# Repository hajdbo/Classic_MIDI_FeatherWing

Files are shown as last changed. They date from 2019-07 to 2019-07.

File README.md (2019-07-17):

# Classic_MIDI_FeatherWing

### _A classic MIDI interface FeatherWing with provisions for DIN-5 and TRS TypeB connectors_

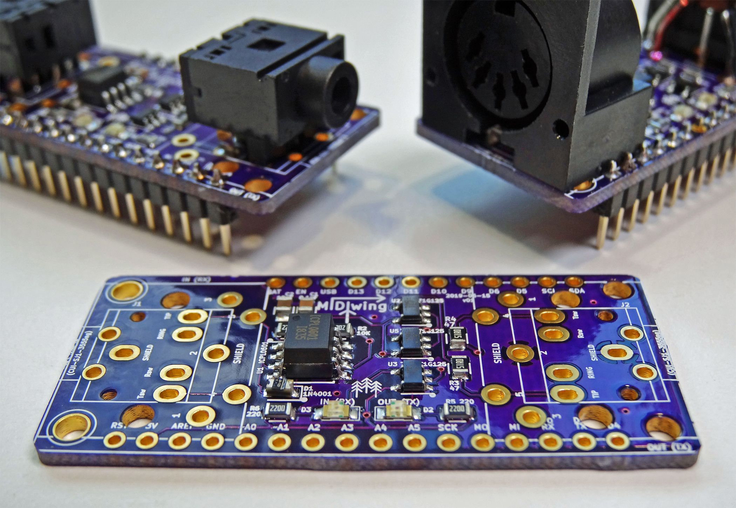
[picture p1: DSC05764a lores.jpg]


The Classic MIDI FeatherWing interface is an Adafruit Feather-compatible module. Deriving its power from the host Feather's 3.3V power, the interface converts incoming and outgoing classic MIDI current-loop input and output to Feather UART (RX and TX) logic pins.

The wing provides on-board input and output footprints for 3.5mm TRS Type B and DIN-5 connectors while maintaining the Feather dimensional format, thanks to John Park's inspirational _Feather MIDI Nub_ design (Twitter: @johnedgarpark). The MIDI input is an optically-isolated connection. MIDI output is buffered and current-limited. On-board receive (RX) and transmit (TX) LEDs indicate incoming and outgoing signals.

DIN-5 MIDI jack used: https://www.adafruit.com/product/1134

3.5mm TRS MIDI jack used: https://www.adafruit.com/product/1699

The Classic MIDI interface was tested with CircuitPython version 4.1.0 beta 1 and earlier releases. Example code is provided in the repository. Additional code examples can be found within the _adafruit__midi_ CircuitPython examples distribution.

OSH Park project: https://oshpark.com/shared_projects/AyVkzfXM

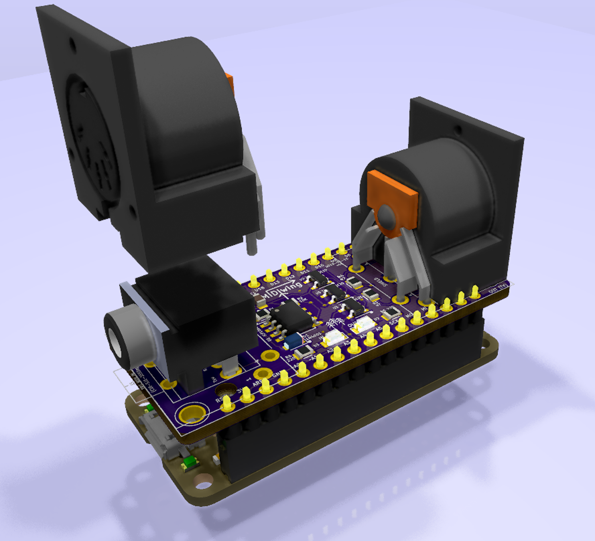
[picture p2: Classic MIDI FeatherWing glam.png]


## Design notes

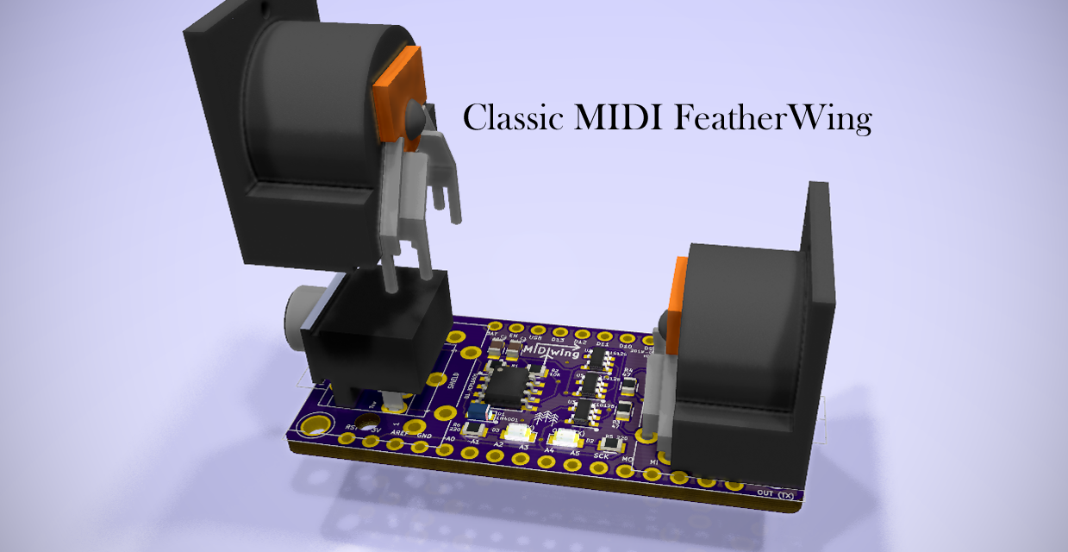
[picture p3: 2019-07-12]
Classic MIDI FeatherWing glam2.png

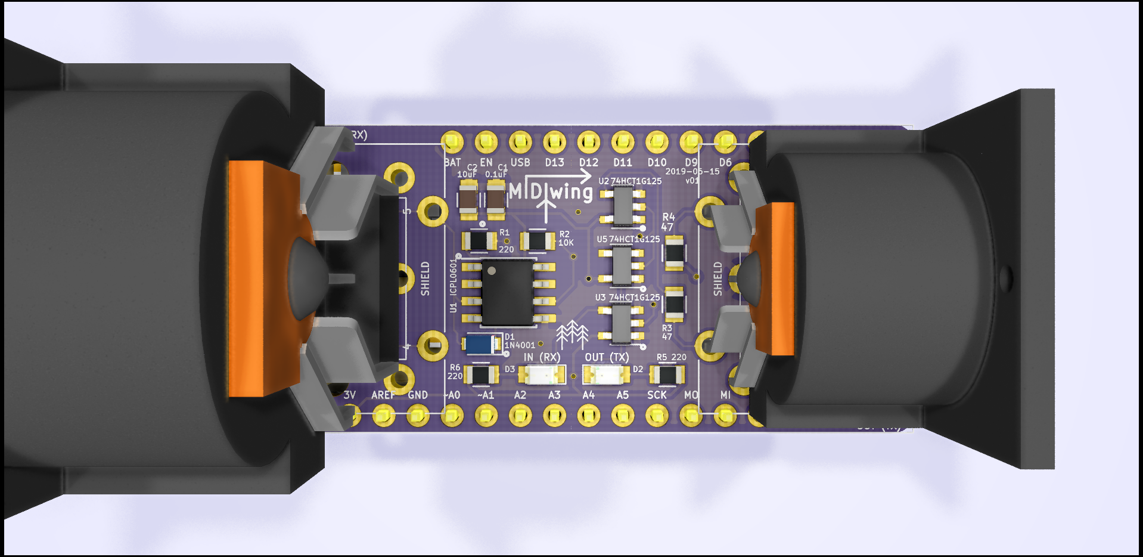
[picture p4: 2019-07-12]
Classic MIDI FeatherWing.png

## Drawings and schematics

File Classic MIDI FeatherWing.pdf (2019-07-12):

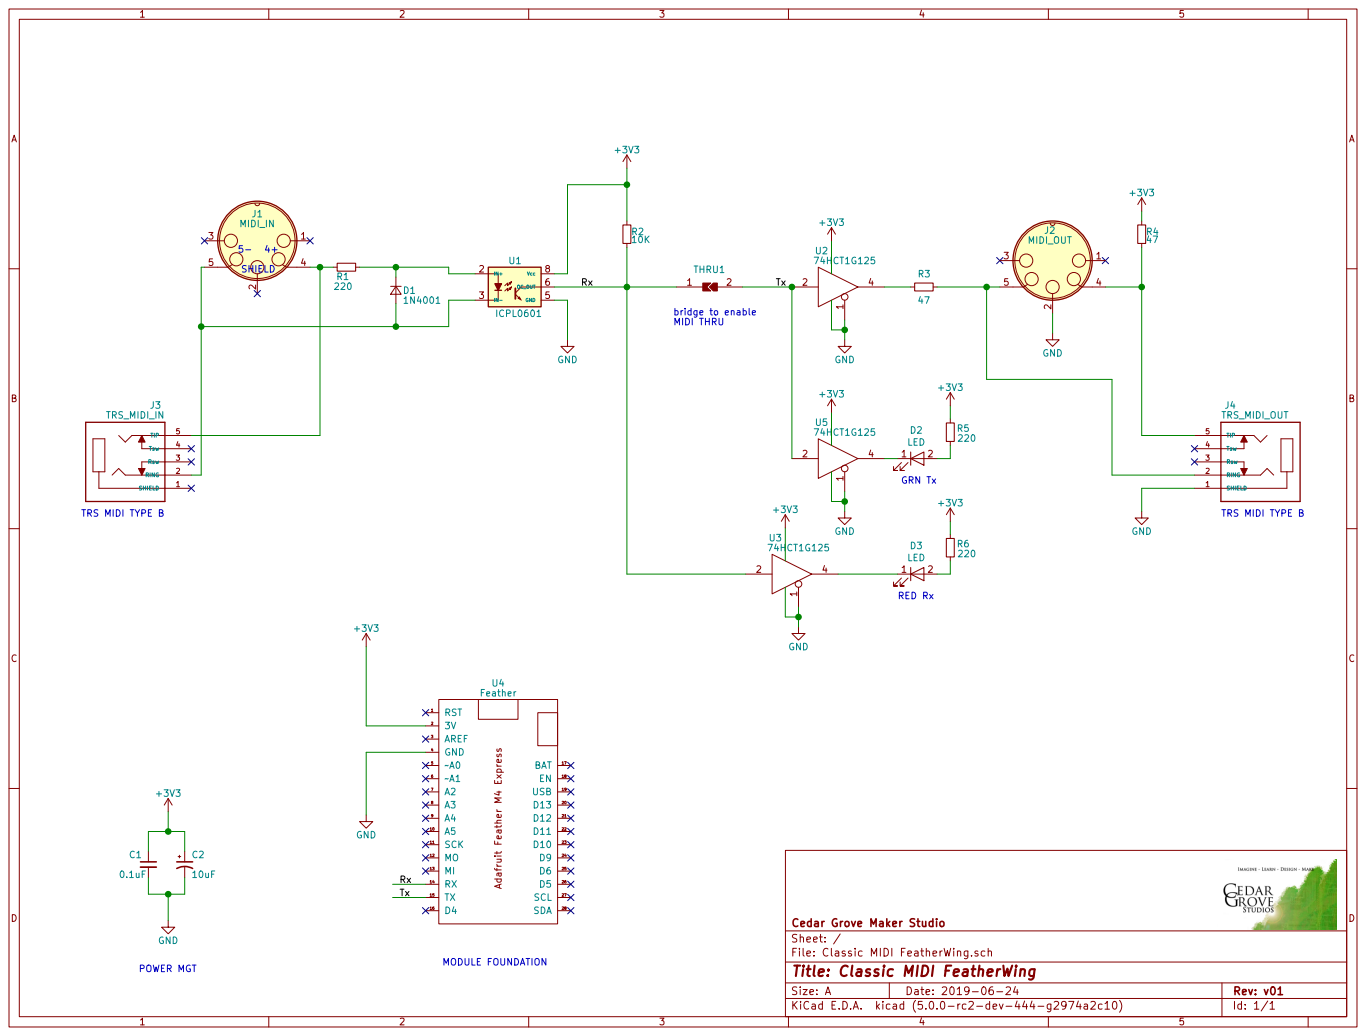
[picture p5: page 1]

220 GRN Tx RED Rx bridge to enable MIDI THRU

File: Classic MIDI FeatherWing.sch Sheet: / Cedar Grove Maker Studio

Id: 1/1 Title: Classic MIDI FeatherWing

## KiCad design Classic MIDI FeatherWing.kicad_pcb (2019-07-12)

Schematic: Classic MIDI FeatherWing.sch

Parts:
C1: 0.1uF; C_0805_HandSoldering
C2: 10uF; C_0805_HandSoldering
D1: 1N4001; D_0805_hand_soldering
D2, D3: LED; LED_0805_HandSoldering
J1: MIDI_IN; CUI_SDS-50J
J2: MIDI_OUT; CUI_SDS-50J
J3: TRS_MIDI_IN; STX-3120-5_3.5mm
J4: TRS_MIDI_OUT; STX-3120-5_3.5mm
R1, R5, R6: 220; R_0805_HandSoldering
R2: 10K; R_0805_HandSoldering
R3, R4: 47; R_0805_HandSoldering
THRU1: Solder_Jumper_0805; 0805_Solder_Jumper
U1: ICPL0601; SOIC-8_3.9x4.9mm_Pitch1.27mm
U2, U3, U5: 74HCT1G125; TSOP-5_1.65x3.05mm_Pitch0.95mm_hand_solder
U4: Feather; Adafruit_Feather_M4_Express_bare

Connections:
+3V3: C1.1, C2.1, R2.1, R4.1, R5.2, R6.2, U1.8 (Vcc), U2.6, U3.6, U4.2, U5.6
/Rx: R2.2, THRU1.1, U1.6 (OC_OUT), U3.2, U4.14
/Tx: THRU1.2, U2.2, U4.15, U5.2
GND: C1.2, C2.2, J2.2, J4.1, U1.5 (GND), U2.1, U2.3, U3.1, U3.3, U4.4, U5.1, U5.3
unnamed: D1.1, R1.2, U1.2 (IN+)
unnamed: D1.2, J1.5, J3.2, U1.3 (IN-)
unnamed: D2.1, U5.4
unnamed: D2.2, R5.1
unnamed: D3.1, U3.4
unnamed: D3.2, R6.1
unnamed: J1.4, J3.5, R1.1
unnamed: J2.4, J4.5, R4.2
unnamed: J2.5, J4.2, R3.1
unnamed: R3.2, U2.4

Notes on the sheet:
SHIELD
POWER MGT
MODULE FOUNDATION
GRN Tx
RED Rx
bridge to enable MIDI THRU
TRS MIDI TYPE B

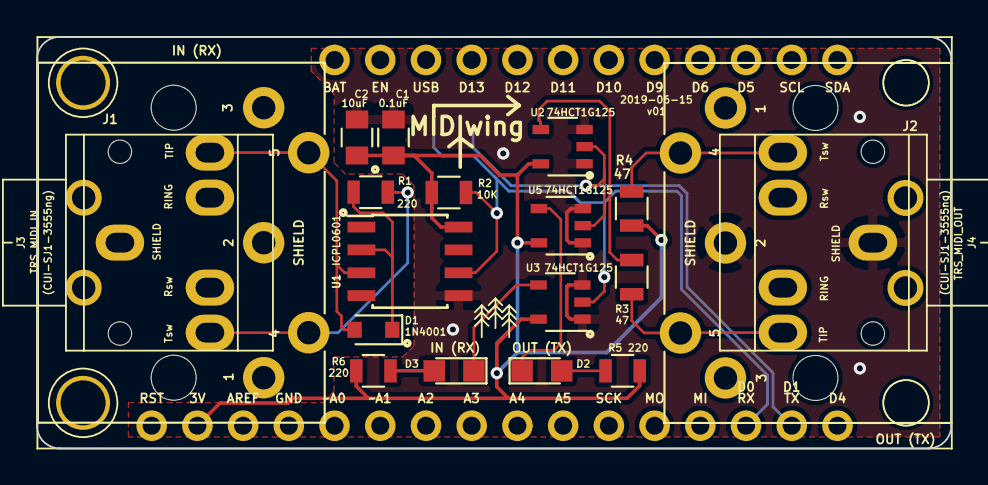
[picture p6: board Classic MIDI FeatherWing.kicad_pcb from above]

Board: 2 copper layers, 50.8 x 22.9 mm, 21 parts (1 on the bottom side), 14 nets.

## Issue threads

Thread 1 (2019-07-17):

order parts

hajdbo, 2019-07-17:
https://lcsc.com/
9x 74HCT1G125GV,125
3x  ICPL0601

find out the resistor/capacitor/led package types

hajdbo, 2019-07-17:
C1	0.1uF	Capacitors_SMD:C_0805_HandSoldering
    C2	10uF	Capacitors_SMD:C_0805_HandSoldering
    D1	1N4001	Adafruit:D_0805_hand_soldering
    D2, D3	LED	LEDs:LED_0805_HandSoldering
    J1	MIDI_IN	Connectors:CUI_SDS-50J
    J2	MIDI_OUT	Connectors:CUI_SDS-50J
    J3	TRS_MIDI_IN	Connectors:STX-3120-5_3.5mm
    J4	TRS_MIDI_OUT	Connectors:STX-3120-5_3.5mm
    R1, R5, R6	220	Resistors_SMD:R_0805_HandSoldering
    R2	10K	Resistors_SMD:R_0805_HandSoldering
    R3, R4	47	Resistors_SMD:R_0805_HandSoldering
    THRU1	Solder_Jumper_0805	Adafruit:0805_Solder_Jumper
    U1	ICPL0601	Housings_SOIC:SOIC-8_3.9x4.9mm_Pitch1.27mm
    U2, U3, U5	74HCT1G125	Adafruit:TSOP-5_1.65x3.05mm_Pitch0.95mm_hand_solder
    U4	Feather	Adafruit:Adafruit_Feather_M4_Express_bare

Closed 2019-07-19.

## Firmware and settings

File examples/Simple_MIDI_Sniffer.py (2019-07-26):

# Simple_MIDI_Sniffer.py
# for Classic MIDI FeatherWing
# 2019-07-16 Cedar Grove Studios
# based upon @kevinjwalter's adafruit_midi library and examples
#

import time
# import usb_midi
import adafruit_midi
import busio
import board

from adafruit_midi.timing_clock            import TimingClock
from adafruit_midi.channel_pressure        import ChannelPressure
from adafruit_midi.control_change          import ControlChange
from adafruit_midi.note_off                import NoteOff
from adafruit_midi.note_on                 import NoteOn
from adafruit_midi.pitch_bend              import PitchBend
from adafruit_midi.polyphonic_key_pressure import PolyphonicKeyPressure
from adafruit_midi.program_change          import ProgramChange
from adafruit_midi.start                   import Start
from adafruit_midi.stop                    import Stop
from adafruit_midi.system_exclusive        import SystemExclusive
from adafruit_midi.midi_message            import MIDIUnknownEvent

from cedargrove_MIDI_util                  import *

UART = busio.UART(board.TX, board.RX, baudrate=31250, timeout=0.001)
midi = adafruit_midi.MIDI(midi_in=UART, midi_out=UART, in_channel=0, out_channel=0)
# 0 is MIDI channel 1

print("Simple_MIDI_Sniffer.py 2019-07-16 CedarGrove")
# Convert channel numbers at the presentation layer to the ones musicians use
print("Input channel:", midi.in_channel + 1 )

t0 = time.monotonic_ns()
tempo = 0

while True:

    msg = midi.receive()

    if msg is not None:
        midi.send(msg)  # MIDI thru
        if isinstance(msg, NoteOn):
            print("NoteOn : #%02d %s %5.3fHz" % (msg.note, note_lexo(msg.note), note_freq(msg.note)))
            print("     vel   %03d     chan #%02d" %(msg.velocity, msg.channel + 1))

        elif isinstance(msg, NoteOff):
            print("NoteOff: #%02d %s %5.3fHz" % (msg.note, note_lexo(msg.note), note_freq(msg.note)))
            print("     vel   %03d     chan #%02d" %(msg.velocity, msg.channel + 1))

        elif isinstance(msg, TimingClock):
            t1 = time.monotonic_ns()
            tempo = (tempo + (1 / ((t1 - t0) * 24) * 60 * 1e9)) / 2 # simple running average
            if (t1-t0) != 0: print("-- Tick: %03.1f BPM" % tempo)  # compared to previous tick
            t0 = time.monotonic_ns()

        elif isinstance(msg, ChannelPressure):
            print("ChannelPressure: ")
            print("     press %03d     chan #%02d" %(msg.pressure, msg.channel + 1))

        elif isinstance(msg, ControlChange):
            print("ControlChange: ctrl #%03d  %s" % (msg.control, cc_decoder(msg.control)))
            print("     value %03d     chan #%02d" %(msg.value, msg.channel + 1))

        elif isinstance(msg, PitchBend):
            print("PitchBend: ")
            print("     bend  %05d   chan #%02d" %(msg.pitch_bend, msg.channel + 1))

        elif isinstance(msg, PolyphonicKeyPressure):
            print("PolyphonicKeyPressure:")
            print("          #%02d %s %5.3fHz" % (msg.note, note_lexo(msg.note), note_freq(msg.note)))
            print("     press %03d     chan #%02d" %(msg.pressure, msg.channel + 1))

        elif isinstance(msg, ProgramChange):
            print("ProgramChange:")
            print("     patch %03d     chan #%02d" %(msg.patch, msg.channel + 1))

        elif isinstance(msg, (Start, Stop)): print("-- %s --" % str(type(msg))[8:-2])

        elif isinstance(msg, SystemExclusive):
            print("SystemExclusive:  ID= ", msg.manufacturer_id,
                ", data= ", msg.data)
            print("--------------------")

        elif isinstance(msg, MIDIUnknownEvent):
            # Message are only known if they are imported
            print("Unknown MIDI event status ", msg.status)

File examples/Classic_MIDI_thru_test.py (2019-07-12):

# Classic_MIDI_thru_test.py
# tests byte-by-byte receiving and transmitting via the uart

import digitalio
import board
import busio

# set up red LED activity indicator
led = digitalio.DigitalInOut(board.D13)
led.direction = digitalio.Direction.OUTPUT

# initialize UART MIDI input and output
uart = busio.UART(board.TX, board.RX, baudrate=31250, timeout=0.001)

print("Classic_MIDI_thru_test.py")

while True:
    data = uart.read(1)  # read a bytearray from the RX pin
    if data is not None:
        led.value = True
        uart.write(data)  # send the bytearray out the TX pin
        led.value = False
